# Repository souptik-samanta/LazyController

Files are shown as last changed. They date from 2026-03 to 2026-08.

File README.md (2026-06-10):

# LazyController

A compact WiFi-enabled relay controller built on a custom PCB. Flip switches, trigger appliances, and automate stuff — all from your phone or browser. No getting up required.

---
BUILD


## What is it?

LazyController is an IoT relay board designed around an ESP-based microcontroller. It exposes relay outputs over WiFi, letting you remotely toggle lights, fans, pumps, or anything else you'd rather not walk over to.

- Custom PCB with onboard relay(s)
- WiFi control via a web interface or serial commands
- Compact form factor — designed to tuck away somewhere tidy
- Production-ready Gerbers included for ordering straight from JLCPCB/PCBWay

---

## Repository Layout

```
LazyController/
├── Cad/          # Enclosure and assembly CAD files
├── Code/         # Firmware source (code.ino)
├── lib/          # README images/assets
├── Pcb/          # KiCad project files (schematic + PCB)
├── production/   # Manufacturing outputs (BOM, positions, netlist, backups)
└── README.md
```

---

## PCB

The board was designed with simplicity in mind — power in, relay out, WiFi in the middle.

<p align="center">
   <img src="./lib/rnder.png" alt="PCB layout"; max-width: 100%; height: auto;" />
</p>

> PCB layout and schematic are in the `Pcb/` folder.  
> Gerbers for direct upload to your fab of choice are in `production/`.
<p align="center">
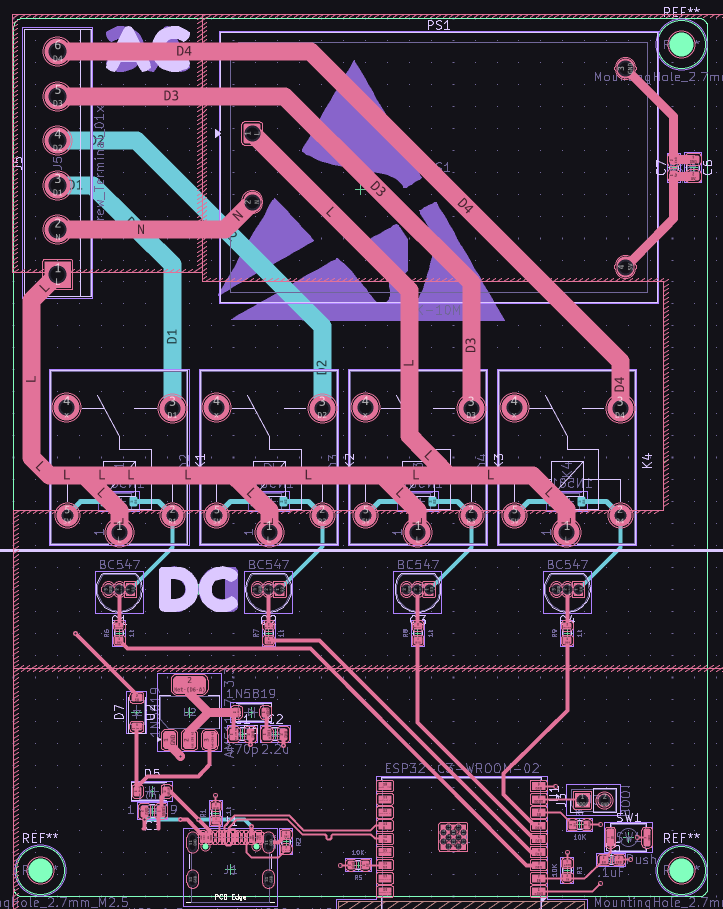
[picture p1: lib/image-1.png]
PCB schematic
   
</p>
Ordering a board:
1. Zip the contents of `production/`
2. Upload to [JLCPCB](https://jlcpcb.com) or [PCBWay](https://www.pcbway.com)
3. Default settings (1.6mm, HASL, FR4) work fine

---
# Schematic

### ESP
<p align="center">
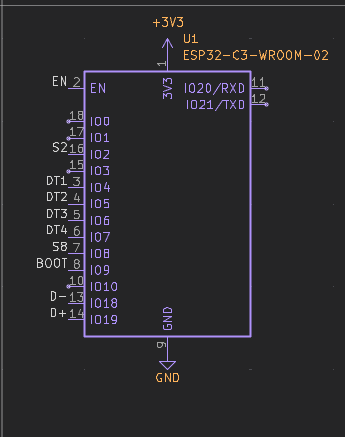
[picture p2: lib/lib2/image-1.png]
ESP schematic
   
</p>

<details>
   <summary><strong>USB</strong></summary>
   <p align="center">
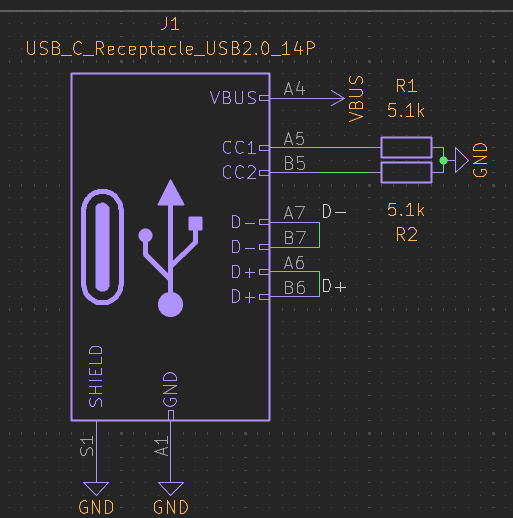
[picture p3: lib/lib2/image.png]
USB schematic
      
   </p>
</details>

<details>
   <summary><strong>Switching</strong></summary>
   <p align="center">
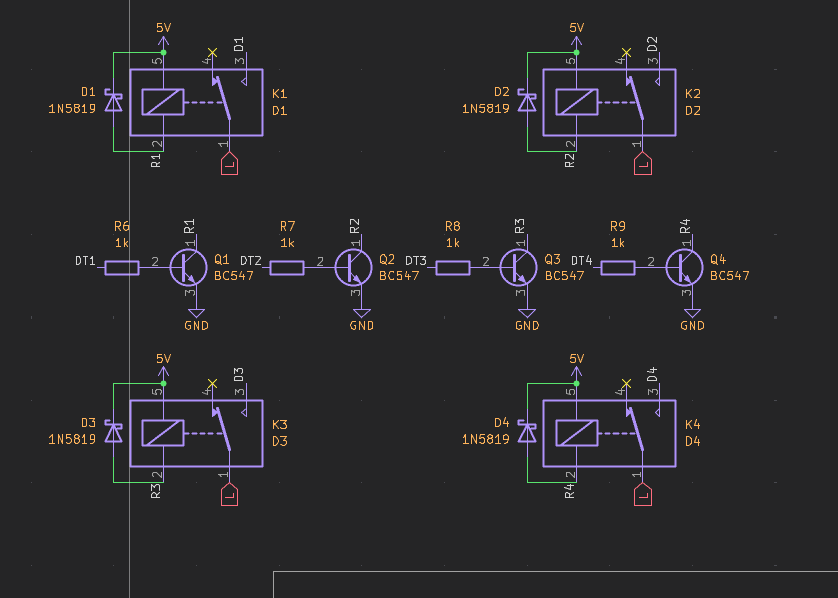
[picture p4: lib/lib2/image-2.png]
Switching schematic
      
   </p>
</details>

<details>
   <summary><strong>ACDC</strong></summary>
   <p align="center">
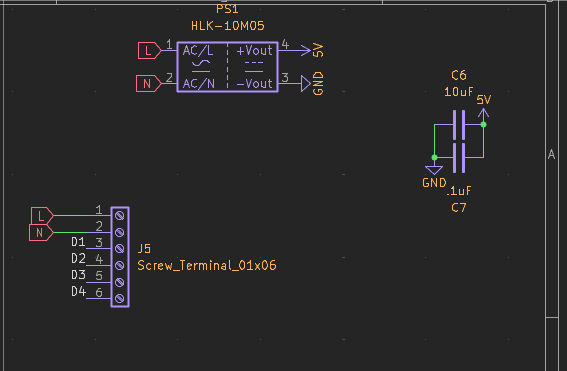
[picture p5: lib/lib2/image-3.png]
ACDC schematic
      
   </p>
</details>

<details>
   <summary><strong>POWER</strong></summary>
   <p align="center">
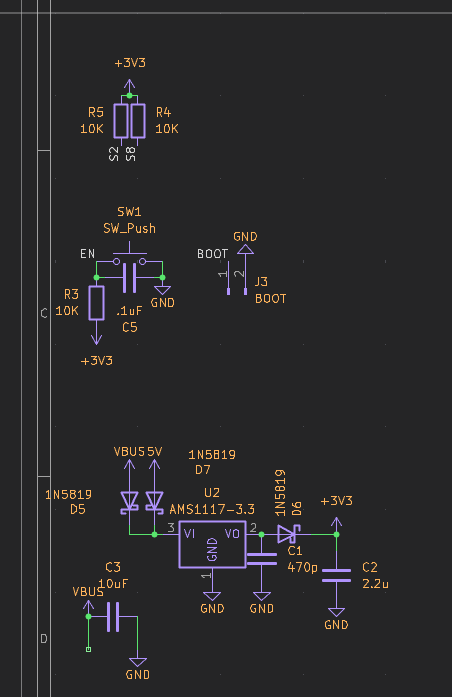
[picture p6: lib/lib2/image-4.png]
POWER schematic
      
   </p>
</details>

## Flashing Firmware

> Make sure you have the [Arduino IDE](https://www.arduino.cc/en/software) or [PlatformIO](https://platformio.org) installed.

1. Add ESP32 board support if you haven't already:
   - In Arduino IDE → Preferences → Additional Board URLs:
     ```
     https://espressif.github.io/arduino-esp32/package_esp32_index.json
     ```
2. Install required libraries:
   - `ESPWiFi` (or `WiFi` for ESP32)
   - `ESPAsyncWebServer` *(recommended)*
3. Open your firmware sketch, set your WiFi credentials:
   ```cpp
   const char* ssid     = "your_network";
   const char* password = "your_password";
   ```
4. Select your board, plug in via USB, and hit **Upload**
5. Open Serial Monitor at `115200 baud` — it'll print the device IP once connected

---

## Wiring

```
Power the controller → relays get activated → each relay switches its connected load.
```

Relay outputs are SPDT — connect your load between **COM** and **NO** (normally open) for off-by-default behaviour.

> If switching mains voltage (120V/230V AC), make sure you take appropriate safety precautions. 

---

## Usage

Once flashed and powered:

1. Connect to the same WiFi network
2. Open a browser and navigate to the IP shown in Serial Monitor
3. Toggle relays from the web UI — or send HTTP requests directly:
   ```
   GET /relay/1/on
   GET /relay/1/off
   ```

---

## BOM

| NAME | DESC | QUAN | PRICE (USD) | PRICE TOT | LINK |
| --- | --- | ---: | ---: | ---: | --- |
| AC DC HLK 10M05 |  | 1 | 3 | 3 | [Link](https://www.google.com/aclk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) |
| 6 Pin 5.08mm Pitch Pluggable Screw Terminal Block |  | 1 | 1 | 1 | [Link](https://robu.in/product/6-pin-5-08mm-pitch-pluggable-screw-terminal-block-pack-of-3/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) |
| RELAY |  | 4 | 1 | 4 | [Link](https://robu.in/product/srd-5vdc-sl-a-ningbo-songle-relay-250vac-5v-15a-1-form-a-1a-spst-no-plugin15-6x19-2mm-power-relays-rohs/) |
| pcb |  | 23 | 1 | 23 |  |
| LCSC |  |  |  |  |  |
| CC0805JRNPO9BN471 | Description | 100 | 0.0074 | 0.74 | [Link](https://www.lcsc.com/product-detail/C62771.html) |
| CL21A225KBQNNNE | 470pF ±5% 50V Ceramic Capacitor NP0 0805 | 10 | 0.0176 | 0.176 | [Link](https://www.lcsc.com/product-detail/C377773.html) |
| GRM21BR61H106KE43L | 2.2uF ±10% 50V Ceramic Capacitor X5R 0805 | 10 | 0.0723 | 0.723 | [Link](https://www.lcsc.com/product-detail/C440198.html) |
| CC0603KRX7R9BB104 | 10uF ±10% 50V Ceramic Capacitor X5R 0805 | 100 | 0.0028 | 0.28 | [Link](https://www.lcsc.com/product-detail/C14663.html) |
| 1N5819W | 100nF ±10% 50V Ceramic Capacitor X7R 0603 | 100 | 0.0072 | 0.72 | [Link](https://www.lcsc.com/product-detail/C963381.html) |
| TYPE-C 16PIN 2MD(073) | Diode Independent 40V 350mA Surface Mount SOD-123 | 20 | 0.0617 | 1.234 | [Link](https://www.lcsc.com/product-detail/C2765186.html) |
| BC547 | USB-C (USB TYPE-C) Receptacle Connector 16 Position Surface Mount, Right Angle | 20 | 0.0302 | 0.604 | [Link](https://www.lcsc.com/product-detail/C47089404.html) |
| FRC0603F5101TS | Bipolar (BJT) Transistor NPN 45V 0.1A 150MHz 625mW Through Hole TO-92 | 100 | 0.0012 | 0.12 | [Link](https://www.lcsc.com/product-detail/C2907044.html) |
| RC0603FR-0710KL | 5.1kΩ ±1% 100mW 0603 Thick Film Resistor | 100 | 0.0013 | 0.13 | [Link](https://www.lcsc.com/product-detail/C98220.html) |
| RC0603FR-071KL | 100mW 10kΩ 75V Thick Film Resistor ±100ppm/℃ ±1% 0603 Chip Resistor - Surface Mount RoHS | 100 | 0.0013 | 0.13 | [Link](https://www.lcsc.com/product-detail/C22548.html) |
| SKRKAEE020 | 100mW 1kΩ 75V Thick Film Resistor ±100ppm/℃ ±1% 0603 Chip Resistor - Surface Mount RoHS | 5 | 0.1309 | 0.6545 | [Link](https://www.lcsc.com/product-detail/C115357.html) |
| ESP32-C3-WROOM-02-N4 | Tactile Switch SPST 2mm 3.9mm x 2.9mm Surface Mount | 1 | 3.0674 | 3.0674 | [Link](https://www.lcsc.com/product-detail/C2934560.html) |
| AMS1117-3.3 | 2.4GHz ESP32-C3 Chip On-board PCB Antenna -105dBm VFQFN-32-EP RF Transceiver Modules and Modems RoHS | 5 | 0.2259 | 1.1295 | [Link](https://www.lcsc.com/product-detail/C6186.html) |
|  | 3.3V 15V Positive Fixed SOT-223 Voltage Regulators - Linear, Low Drop Out (LDO) Regulators RoHS |  |  |  |  |
|  |  |  |  |  |  |
|  |  | TOTAL |  | 50.7084 |  |

- Full BOM sheet: [Open Google Sheet](https://docs.google.com/spreadsheets/d/1Jlhe0WWFfPgNdCmWaUOwISSQ84eng0tOMz2COa2eSn8/edit?usp=sharing)

## YouTube
- [Project video](https://youtu.be/daNDijgMs3k)
- More videos soon.

## Contact
- Email: [me@souptik.me](mailto:me@souptik.me)
- Slack: @Souptik Samanta

## Funding / Support
- Blueprint
- HackClub
---

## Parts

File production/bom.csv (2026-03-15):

Designator | Footprint | Quantity | Value | LCSC Part #
C1 | 0805 | 1 | 470p
C2 | 0805 | 1 | 2.2u
C3, C6 | 0805 | 2 | 10uF
C5, C7 | 0603 | 2 | .1uF
D1, D2, D3, D4, D5, D6, D7 | D_SOD-123 | 7 | 1N5819
J1 | USB_C_Receptacle_GCT_USB4105-xx-A_16P_TopMnt_Horizontal | 1 | USB_C_Receptacle_USB2.0_14P
J3 | PinHeader_1x02_P2.54mm_Vertical | 1 | BOOT
J5 | TerminalBlock_bornier-6_P5.08mm | 1 | Screw_Terminal_01x06
K1 | Relay_SPDT_SANYOU_SRD_Series_Form_C | 1 | D1
K2 | Relay_SPDT_SANYOU_SRD_Series_Form_C | 1 | D2
K3 | Relay_SPDT_SANYOU_SRD_Series_Form_C | 1 | D3
K4 | Relay_SPDT_SANYOU_SRD_Series_Form_C | 1 | D4
PS1 | Converter_ACDC_Hi-Link_HLK-10Mxx | 1 | HLK-10M05
Q1, Q2, Q3, Q4 | TO-92_Inline | 4 | BC547
R1, R2 | 0603 | 2 | 5.1k
R3, R4, R5 | 0603 | 3 | 10K
R6, R7, R8, R9 | 0603 | 4 | 1k
SW1 | SW_Push_SPST_NO_Alps_SKRK | 1 | SW_Push
U1 | ESP32-C3-WROOM-02 | 1 | ESP32-C3-WROOM-02
U2 | SOT-223-3_TabPin2 | 1 | AMS1117-3.3

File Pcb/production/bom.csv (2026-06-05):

Designator | Footprint | Quantity | Value | LCSC Part #
C1 | 0805 | 1 | 470p
C2 | 0805 | 1 | 2.2u
C3, C6 | 0805 | 2 | 10uF
C7 | 0603 | 1 | .1uF
D1, D2, D3, D4, D5, D6, D7 | D_SOD-123 | 7 | 1N5819
DL1, DL2, DL3, DL4, DL5 | 0805 | 5 | LED
J1 | USB_C_Receptacle_GCT_USB4105-xx-A_16P_TopMnt_Horizontal | 1 | USB_C_Receptacle_USB2.0_14P
J2 | PinHeader_1x05_P2.54mm_Vertical | 1 | Conn_01x05_Pin
J5 | TerminalBlock_bornier-6_P5.08mm | 1 | Screw_Terminal_01x06
K1 | Relay_SPDT_SANYOU_SRD_Series_Form_C | 1 | D1
K2 | Relay_SPDT_SANYOU_SRD_Series_Form_C | 1 | D2
K3 | Relay_SPDT_SANYOU_SRD_Series_Form_C | 1 | D3
K4 | Relay_SPDT_SANYOU_SRD_Series_Form_C | 1 | D4
PS1 | Converter_ACDC_Hi-Link_HLK-10Mxx | 1 | HLK-10M05
Q1, Q2, Q3, Q4 | TO-92_Inline | 4 | BC547
R1, R2 | 0603 | 2 | 5.1k
R10, R11 | 0603 | 2 | 330
R3, R4, R5 | 0603 | 3 | 220
R6, R7, R8, R9 | 0603 | 4 | 1k
U2 | SOT-223-3_TabPin2 | 1 | AMS1117-3.3
U3 | XIAO-ESP32S3-DIP | 1 | XIAO-ESP32-S3-DIP

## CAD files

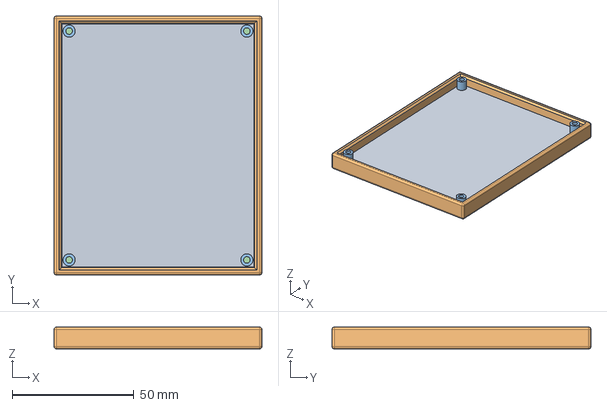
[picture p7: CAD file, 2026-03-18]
Cad/lazyahh_case.step
85.5 x 106.5 x 9.00 mm

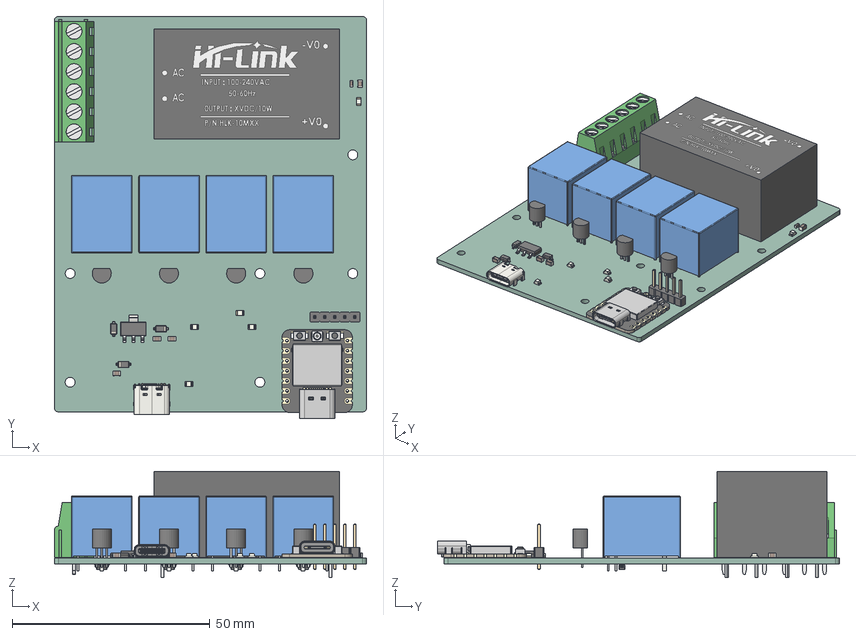
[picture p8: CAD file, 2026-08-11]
Pcb/Body.step
79.0 x 101.7 x 26.8 mm
LED_0805_2012Metric x 5
TO-92_Inline_Narrow x 4
D_SOD-123 x 7
BOSS-EXTRUDE14_8_
BOSS-EXTRUDE7_4_
BOSS-EXTRUDE7_3_
BOSS-EXTRUDE14_4_
BOSS-EXTRUDE14_2_
BOSS-EXTRUDE14_11_
BOSS-EXTRUDE7_7_
BOSS-EXTRUDE14_9_
BOSS-EXTRUDE14_3_
BOSS-EXTRUDE14_7_
MIRROR2
BOSS-EXTRUDE14_5_
BOSS-EXTRUDE14_12_
BOSS-EXTRUDE7_8_
BOSS-EXTRUDE7_1_
BOSS-EXTRUDE14_10_
BOSS-EXTRUDE7_9_
BOSS-EXTRUDE14_6_
BOSS-EXTRUDE14_1_
BOSS-EXTRUDE7_6_
BOSS-EXTRUDE7_2_
CUT-EXTRUDE5
BOSS-EXTRUDE7_5_
U.FL Connector v1
Button (1) x 2
Shield
Relay_SPDT_SANYOU_SRD_Series_Form_C x 4
C_0805_2012Metric x 4
Pin (1) (19) (1) (1) (1) (1)
Tornillo (1) (19) (1) (1) (1) (1)
Cubo interno (1) (19) (1) (1) (1) (1)
Pin (1) (1) (18) (1) (1) (1) (1)
Tornillo (1) (1) (18) (1) (1) (1) (1)
Cubo interno (1) (1) (18) (1) (1) (1) (1)
Pin (1) (11) (1) (1) (1) (1)
Tornillo (1) (11) (1) (1) (1) (1)
Cubo interno (1) (11) (1) (1) (1) (1)
Pin (1) (1) (10) (1) (1) (1) (1)
Tornillo (1) (1) (10) (1) (1) (1) (1)
Cubo interno (1) (1) (10) (1) (1) (1) (1)
Pin (1) (17) (1) (1) (1)
Tornillo (1) (17) (1) (1) (1)
Cubo interno (1) (17) (1) (1) (1)
Pin (1) (1) (16) (1) (1) (1)
Tornillo (1) (1) (16) (1) (1) (1)
Cubo interno (1) (1) (16) (1) (1) (1)
Pin (1) (18) (1) (1)
Tornillo (1) (18) (1) (1)
Cubo interno (1) (18) (1) (1)
Pin (1) (1) (17) (1) (1)
Tornillo (1) (1) (17) (1) (1)
Cubo interno (1) (1) (17) (1) (1)
Pin (1) (20) (1)
Tornillo (1) (20) (1)
Cubo interno (1) (20) (1)
Pin (1) (1) (19) (1)
Tornillo (1) (1) (19) (1)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

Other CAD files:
Cad/lazyahh_asm.f3z

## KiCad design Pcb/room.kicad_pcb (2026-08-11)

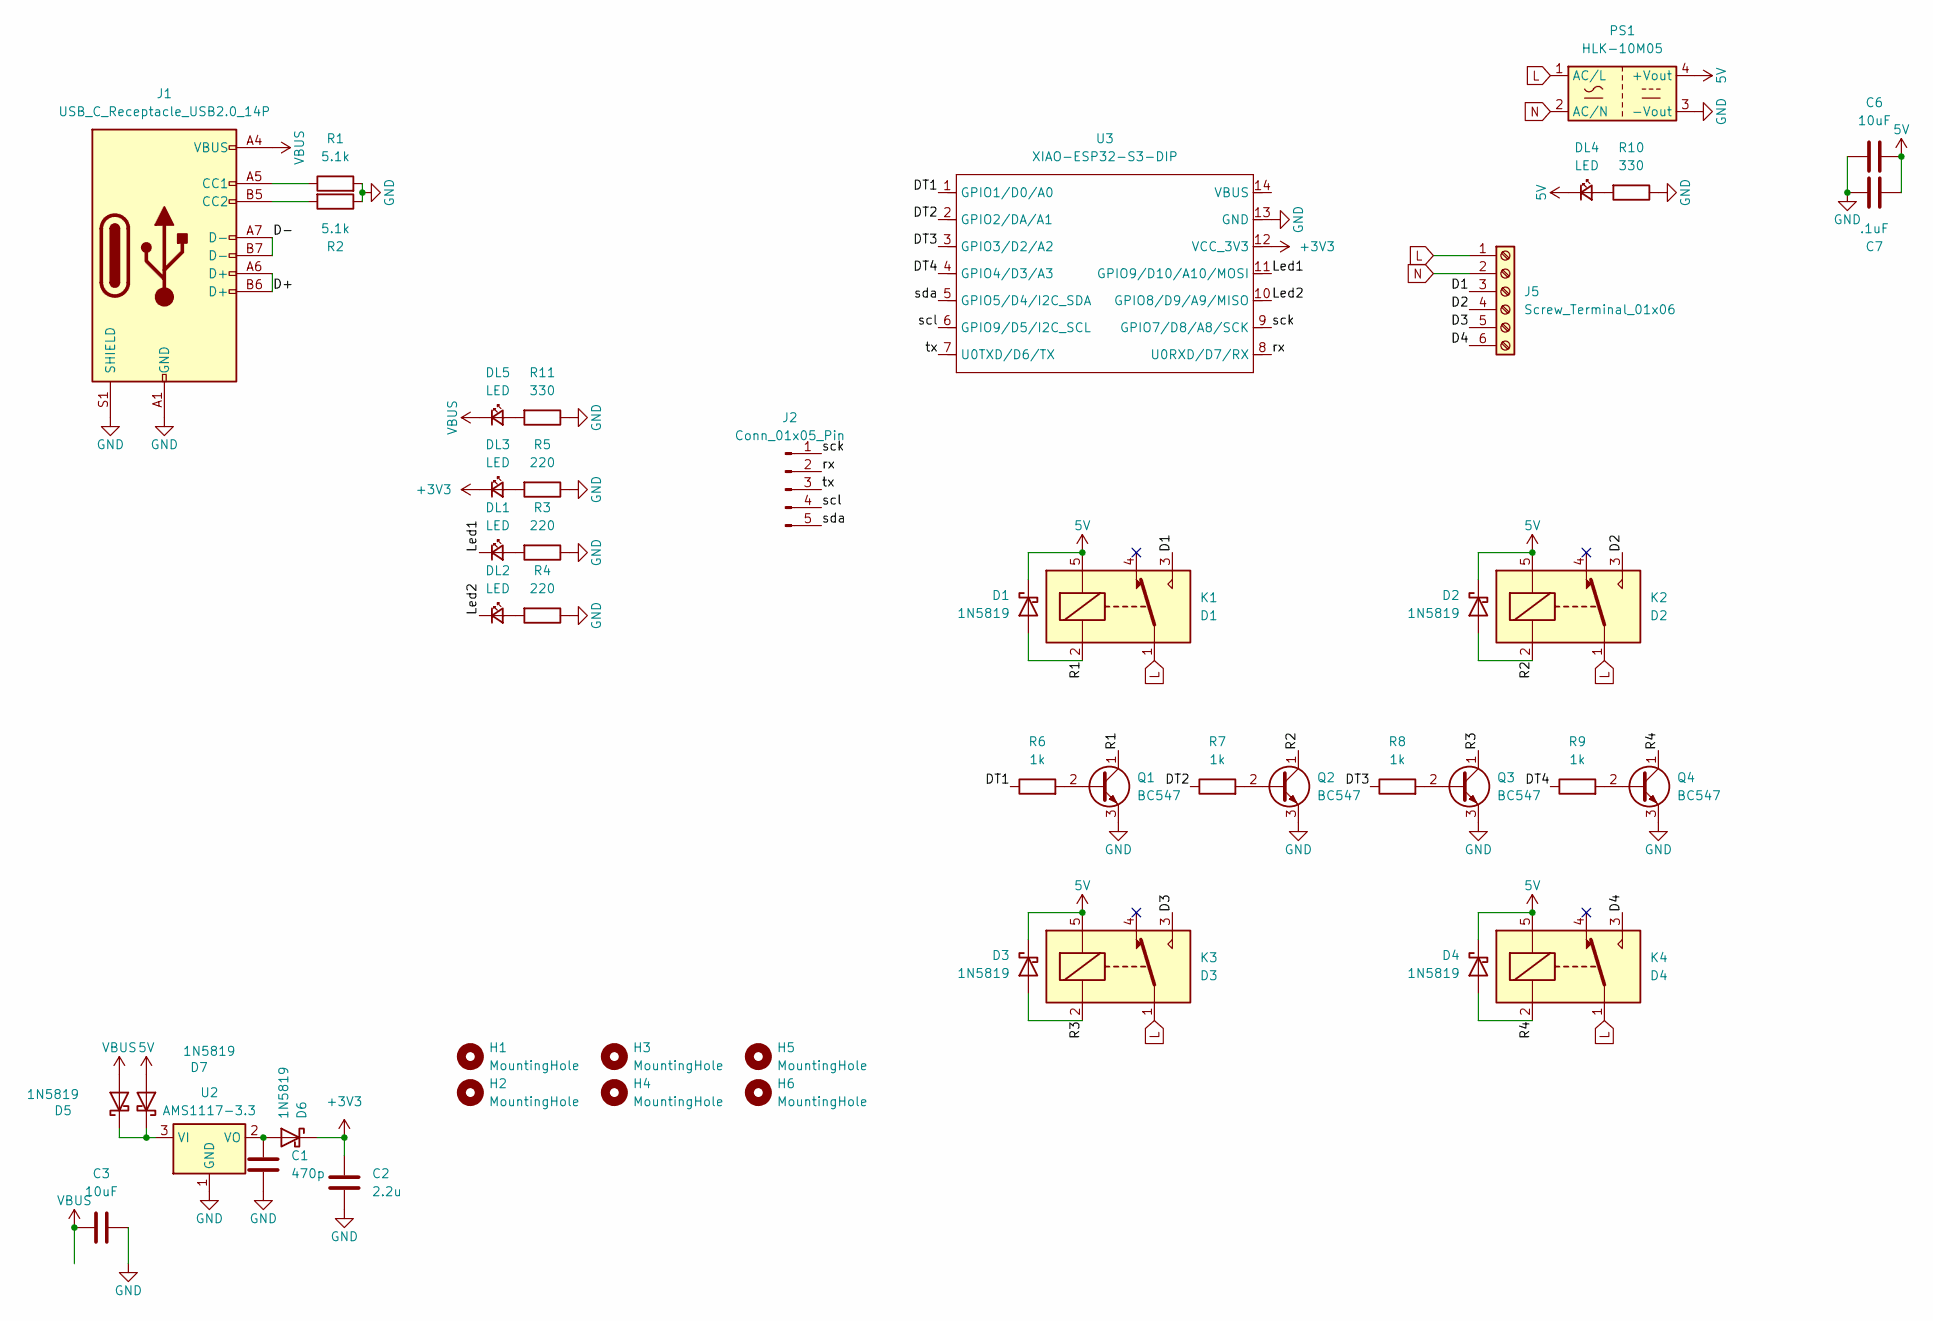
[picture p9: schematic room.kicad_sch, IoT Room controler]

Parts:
C1: 470p; C_0805_2012Metric
C2: 2.2u; C_0805_2012Metric
C3, C6: 10uF; C_0805_2012Metric
C7: .1uF; C_0603_1608Metric_Pad1.08x0.95mm_HandSolder
D1, D2, D3, D4, D5, D6, D7: 1N5819; D_SOD-123
DL1, DL2, DL3, DL4, DL5: LED; LED_0805_2012Metric_Pad1.15x1.40mm_HandSolder
H1, H2, H3, H4, H5, H6: MountingHole; MountingHole_2.5mm
J1: USB_C_Receptacle_USB2.0_14P; USB_C_Receptacle_GCT_USB4105-xx-A_16P_TopMnt_Horizontal
J2: Conn_01x05_Pin; PinHeader_1x05_P2.54mm_Vertical
J5: Screw_Terminal_01x06; TerminalBlock_bornier-6_P5.08mm
K1: D1; Relay_SPDT_SANYOU_SRD_Series_Form_C
K2: D2; Relay_SPDT_SANYOU_SRD_Series_Form_C
K3: D3; Relay_SPDT_SANYOU_SRD_Series_Form_C
K4: D4; Relay_SPDT_SANYOU_SRD_Series_Form_C
PS1: HLK-10M05; Converter_ACDC_Hi-Link_HLK-10Mxx
Q1, Q2, Q3, Q4: BC547; TO-92_Inline
R1, R2: 5.1k; R_0603_1608Metric
R3, R4, R5: 220; R_0603_1608Metric
R6, R7, R8, R9: 1k; R_0603_1608Metric
R10, R11: 330; R_0603_1608Metric
U2: AMS1117-3.3; SOT-223-3_TabPin2
U3: XIAO-ESP32-S3-DIP; XIAO-ESP32S3-DIP

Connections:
5V: C6.2, C7.1, D1.1 (K), D2.1 (K), D3.1 (K), D4.1 (K), D7.2 (A), DL4.1 (K), K1.5, K2.5, K3.5, K4.5, PS1.4 (+Vout)
+3V3: C2.1, D6.1 (K), DL3.1 (K), U3.12 (VCC_3V3)
/D1: J5.3, K1.3
/D2: J5.4, K2.3
/D3: J5.5, K3.3
/D4: J5.6, K4.3
/D+: J1.A6 (D+), J1.B6 (D+)
/D-: J1.A7 (D-), J1.B7 (D-)
/DT1: R6.1, U3.1 (GPIO1/D0/A0)
/DT2: R7.1, U3.2 (GPIO2/DA/A1)
/DT3: R8.1, U3.3 (GPIO3/D2/A2)
/DT4: R9.1, U3.4 (GPIO4/D3/A3)
/Led1: DL1.1 (K), U3.11 (GPIO9/D10/A10/MOSI)
/Led2: DL2.1 (K), U3.10 (GPIO8/D9/A9/MISO)
/R1: D1.2 (A), K1.2, Q1.1 (C)
/R2: D2.2 (A), K2.2, Q2.1 (C)
/R3: D3.2 (A), K3.2, Q3.1 (C)
/R4: D4.2 (A), K4.2, Q4.1 (C)
/rx: J2.2, U3.8 (U0RXD/D7/RX)
/sck: J2.1, U3.9 (GPIO7/D8/A8/SCK)
/scl: J2.4, U3.6 (GPIO9/D5/I2C_SCL)
/sda: J2.5, U3.5 (GPIO5/D4/I2C_SDA)
/tx: J2.3, U3.7 (U0TXD/D6/TX)
GND: C1.2, C2.2, C3.2, C6.1, C7.2, J1.A1 (GND), J1.A12 (GND), J1.B1 (GND), J1.B12 (GND), J1.S1 (SHIELD), PS1.3 (-Vout), Q1.3 (E), Q2.3 (E), Q3.3 (E), Q4.3 (E), R1.2, R2.1, R3.1, R4.1, R5.1, R10.1, R11.1, U2.1 (GND), U3.13 (GND)
L: J5.1, K1.1, K2.1, K3.1, K4.1, PS1.1 (AC/L)
N: J5.2, PS1.2 (AC/N)
unnamed: D5.1 (K), D7.1 (K), U2.3 (VI)
unnamed: C1.1, D6.2 (A), U2.2 (VO)
unnamed: DL1.2 (A), R3.2
unnamed: DL2.2 (A), R4.2
unnamed: DL3.2 (A), R5.2
unnamed: DL4.2 (A), R10.2
unnamed: DL5.2 (A), R11.2
unnamed: J1.A5 (CC1), R1.1
unnamed: J1.B5 (CC2), R2.2
unnamed: Q1.2 (B), R6.2
unnamed: Q2.2 (B), R7.2
unnamed: Q3.2 (B), R8.2
unnamed: Q4.2 (B), R9.2
VBUS: C3.1, D5.2 (A), DL5.1 (K), J1.A4 (VBUS), J1.A9 (VBUS), J1.B4 (VBUS), J1.B9 (VBUS)

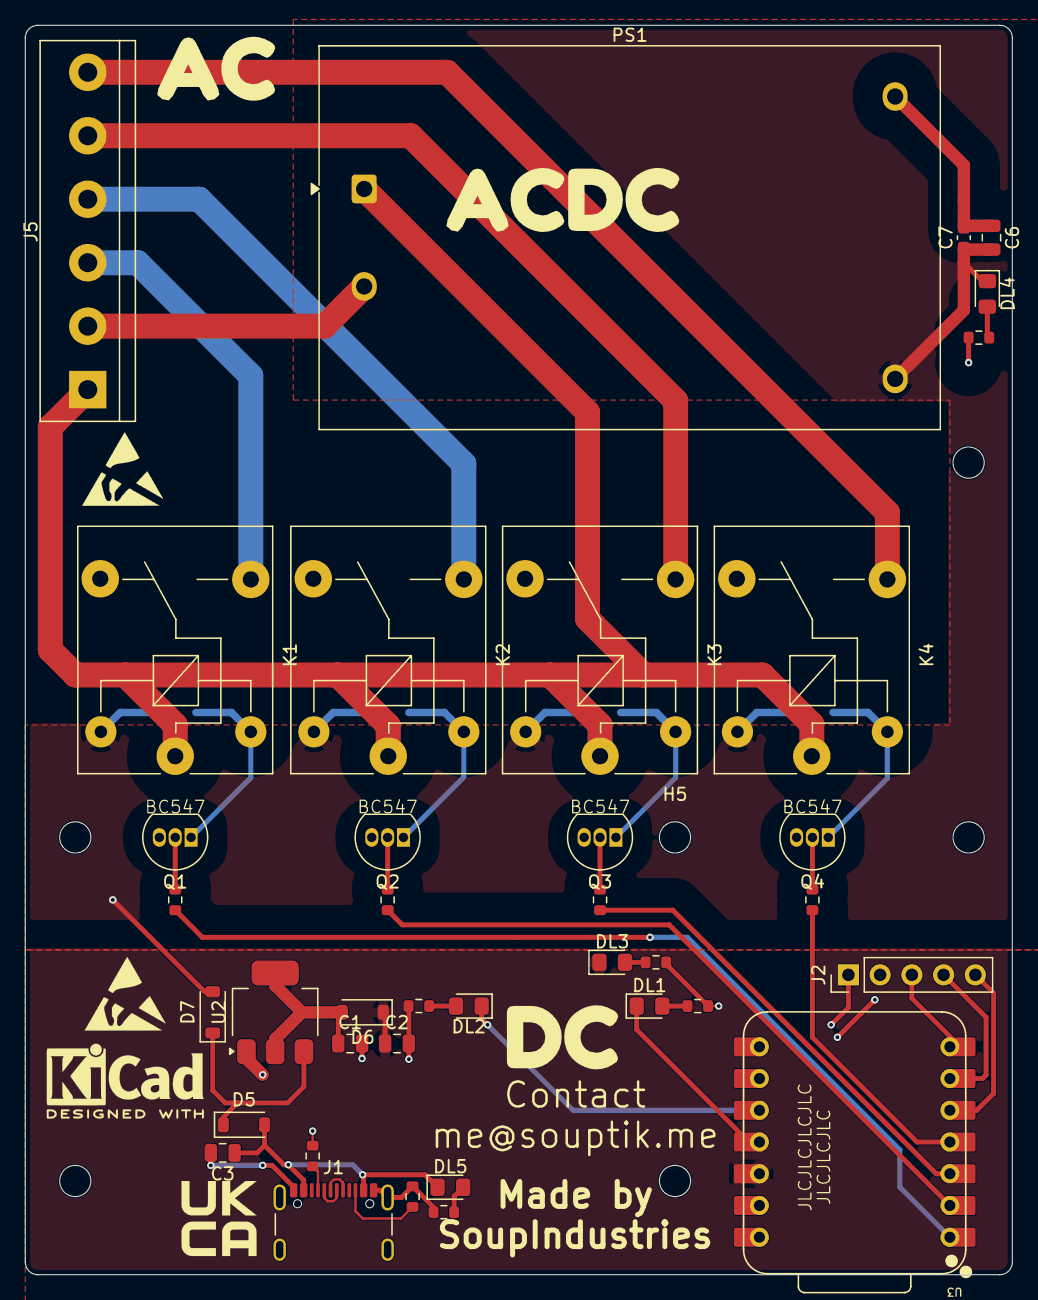
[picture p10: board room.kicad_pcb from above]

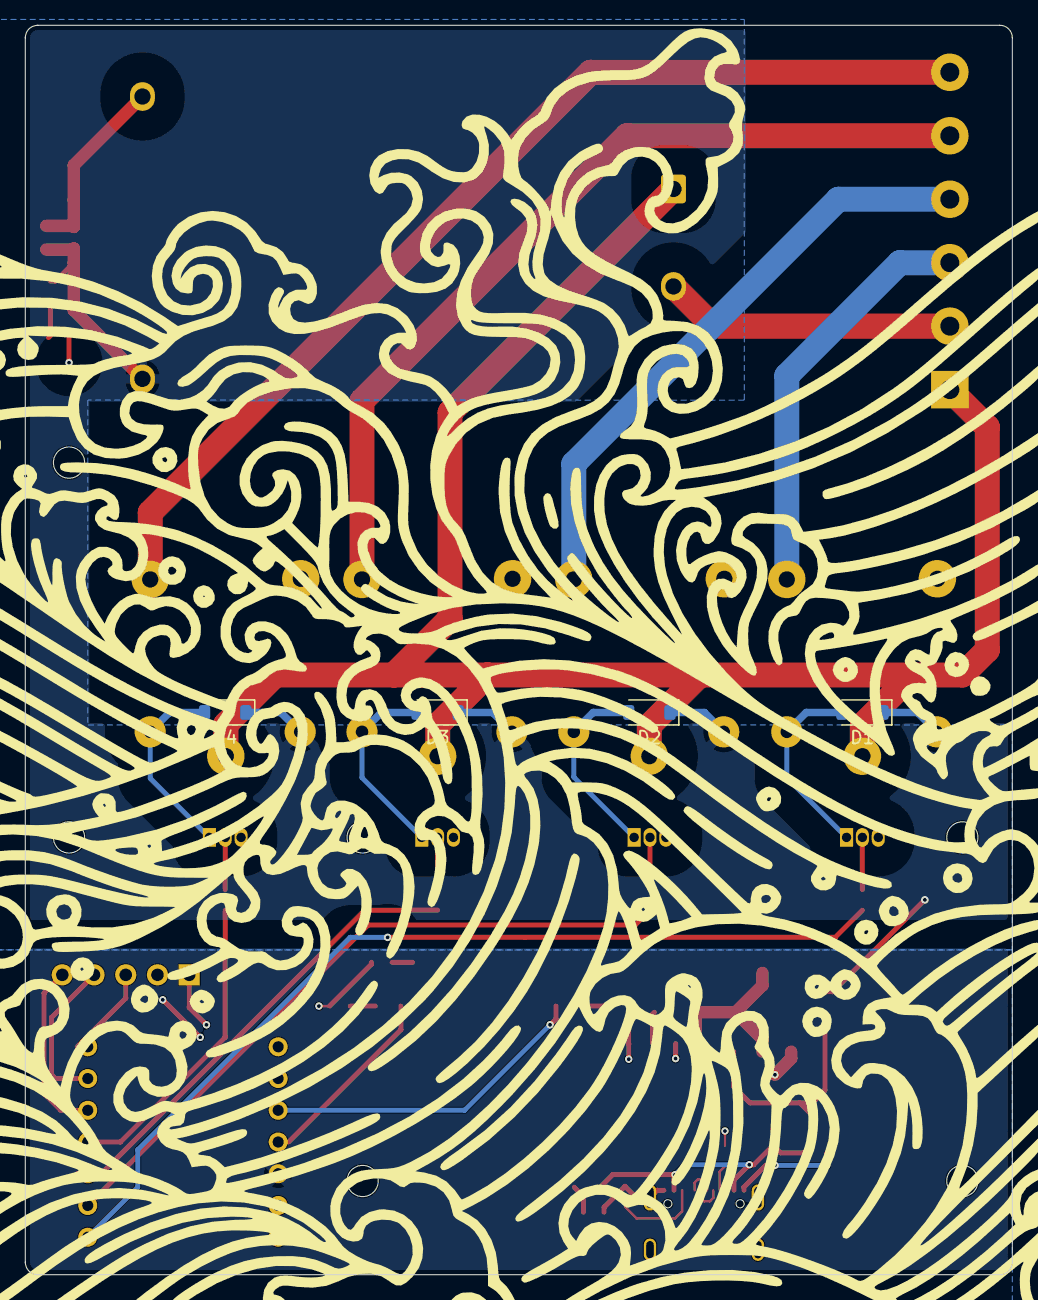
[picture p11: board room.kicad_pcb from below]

Board: 4 copper layers, 79.0 x 100.0 mm, 51 parts (4 on the bottom side), 40 nets.

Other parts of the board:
kibuzzard-69B63945: G***; kibuzzard-69B63945
kibuzzard-69B63969: G***; kibuzzard-69B63969
kibuzzard-69C64D69: G***; kibuzzard-69C64D69

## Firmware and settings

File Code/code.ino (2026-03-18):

/*
  LazyController — 4 Relay WiFi Controller
  MCU: ESP32-C3-WROOM-02
  Transistors: BC547 (NPN, active HIGH)
  
  Relay GPIOs — adjust to match your PCB traces:
  Relay 1 → GPIO2
  Relay 2 → GPIO3
  Relay 3 → GPIO4
  Relay 4 → GPIO5
*/

#include <WiFi.h>
#include <WebServer.h>

// ─── Config ───────────────────────────────────────────────
const char* SSID     = "your_wifi_ssid";
const char* PASSWORD = "your_wifi_password";

const int RELAY_PINS[4] = {2, 3, 4, 5};  // adjust if needed
bool relayState[4]      = {false, false, false, false};

WebServer server(80);

// ─── HTML UI ──────────────────────────────────────────────
const char INDEX_HTML[] PROGMEM = R"rawliteral(
<!DOCTYPE html>
<html>
<head>
  <meta charset="UTF-8">
  <meta name="viewport" content="width=device-width, initial-scale=1">
  <title>LazyController</title>
  <style>
    * { box-sizing: border-box; margin: 0; padding: 0; }
    body {
      font-family: monospace;
      background: #0f0f0f;
      color: #e0e0e0;
      display: flex;
      flex-direction: column;
      align-items: center;
      min-height: 100vh;
      padding: 40px 16px;
    }
    h1 { font-size: 1.4rem; letter-spacing: 0.15em; color: #fff; margin-bottom: 6px; }
    p.sub { font-size: 0.75rem; color: #555; margin-bottom: 40px; }
    .grid { display: grid; grid-template-columns: 1fr 1fr; gap: 16px; width: 100%; max-width: 380px; }
    .card {
      background: #1a1a1a;
      border: 1px solid #2a2a2a;
      border-radius: 12px;
      padding: 24px 16px;
      display: flex;
      flex-direction: column;
      align-items: center;
      gap: 14px;
    }
    .label { font-size: 0.7rem; color: #777; letter-spacing: 0.1em; text-transform: uppercase; }
    .dot {
      width: 12px; height: 12px;
      border-radius: 50%;
      background: #2a2a2a;
      box-shadow: 0 0 0 3px #1a1a1a;
      transition: background 0.2s, box-shadow 0.2s;
    }
    .dot.on { background: #00e676; box-shadow: 0 0 8px #00e676aa; }
    .btn {
      width: 100%;
      padding: 10px;
      border: none;
      border-radius: 8px;
      background: #222;
      color: #ccc;
      font-family: monospace;
      font-size: 0.8rem;
      cursor: pointer;
      transition: background 0.15s, color 0.15s;
      letter-spacing: 0.08em;
    }
    .btn:hover { background: #2e2e2e; color: #fff; }
    .btn.on { background: #00c853; color: #000; }
    .btn.on:hover { background: #00e676; }
    .all-row { display: flex; gap: 10px; width: 100%; max-width: 380px; margin-top: 24px; }
    .all-row .btn { flex: 1; }
  </style>
</head>
<body>
  <h1>LazyController</h1>
  <p class="sub">ESP32-C3 · 4 relay · WiFi</p>

  <div class="grid" id="grid"></div>

  <div class="all-row">
    <button class="btn" onclick="allRelays(true)">ALL ON</button>
    <button class="btn" onclick="allRelays(false)">ALL OFF</button>
  </div>

  <script>
    let states = [false, false, false, false];

    function buildUI() {
      const grid = document.getElementById('grid');
      grid.innerHTML = '';
      states.forEach((on, i) => {
        grid.innerHTML += `
          <div class="card">
            <div class="dot ${on ? 'on' : ''}" id="dot${i}"></div>
            <span class="label">Relay ${i + 1}</span>
            <button class="btn ${on ? 'on' : ''}" onclick="toggle(${i})">
              ${on ? 'ON' : 'OFF'}
            </button>
          </div>`;
      });
    }

    async function fetchStates() {
      const res = await fetch('/state');
      states = await res.json();
      buildUI();
    }

    async function toggle(i) {
      await fetch(`/relay/${i + 1}/${states[i] ? 'off' : 'on'}`);
      fetchStates();
    }

    async function allRelays(on) {
      await fetch(`/all/${on ? 'on' : 'off'}`);
      fetchStates();
    }

    fetchStates();
    setInterval(fetchStates, 3000);
  </script>
</body>
</html>
)rawliteral";

// ─── Handlers ─────────────────────────────────────────────
void handleRoot() {
  server.send(200, "text/html", INDEX_HTML);
}

void handleState() {
  String json = "[";
  for (int i = 0; i < 4; i++) {
    json += relayState[i] ? "true" : "false";
    if (i < 3) json += ",";
  }
  json += "]";
  server.send(200, "application/json", json);
}

void handleRelay() {
  // URL: /relay/{1-4}/{on|off}
  String uri = server.uri();  // e.g. /relay/2/on
  int relayNum = uri.charAt(7) - '0';  // char at index 7 = relay number
  bool turnOn  = uri.endsWith("on");

  if (relayNum >= 1 && relayNum <= 4) {
    int idx = relayNum - 1;
    relayState[idx] = turnOn;
    digitalWrite(RELAY_PINS[idx], turnOn ? HIGH : LOW);
    server.send(200, "text/plain", turnOn ? "on" : "off");
  } else {
    server.send(400, "text/plain", "bad relay number");
  }
}

void handleAll() {
  bool turnOn = server.uri().endsWith("on");
  for (int i = 0; i < 4; i++) {
    relayState[i] = turnOn;
    digitalWrite(RELAY_PINS[i], turnOn ? HIGH : LOW);
  }
  server.send(200, "text/plain", "ok");
}

// ─── Setup ────────────────────────────────────────────────
void setup() {
  Serial.begin(115200);

  // Init relay pins
  for (int i = 0; i < 4; i++) {
    pinMode(RELAY_PINS[i], OUTPUT);
    digitalWrite(RELAY_PINS[i], LOW);  // relays OFF on boot
  }

  // Connect WiFi
  Serial.printf("\nConnecting to %s", SSID);
  WiFi.begin(SSID, PASSWORD);
  while (WiFi.status() != WL_CONNECTED) {
    delay(500);
    Serial.print(".");
  }
  Serial.printf("\nConnected! IP: %s\n", WiFi.localIP().toString().c_str());

  // Routes
  server.on("/",          HTTP_GET, handleRoot);
  server.on("/state",     HTTP_GET, handleState);
  server.onNotFound([&]() {
    String uri = server.uri();
    if (uri.startsWith("/relay/")) handleRelay();
    else if (uri.startsWith("/all/"))  handleAll();
    else server.send(404, "text/plain", "not found");
  });

  server.begin();
  Serial.println("HTTP server started.");
}

// ─── Loop ─────────────────────────────────────────────────
void loop() {
  server.handleClient();
}

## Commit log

2026-03-15 Mostly done
    [bom.csv, designators.csv, positions.csv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]
2026-03-18 all done
    [bom.csv, designators.csv, lazyahh_asm.f3z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]
2026-06-05 Final update for pcb
    [bom.csv, designators.csv, positions.csv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]
